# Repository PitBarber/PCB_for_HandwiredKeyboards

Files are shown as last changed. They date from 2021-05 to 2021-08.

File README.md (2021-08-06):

# PCB for Handwired Keyboards

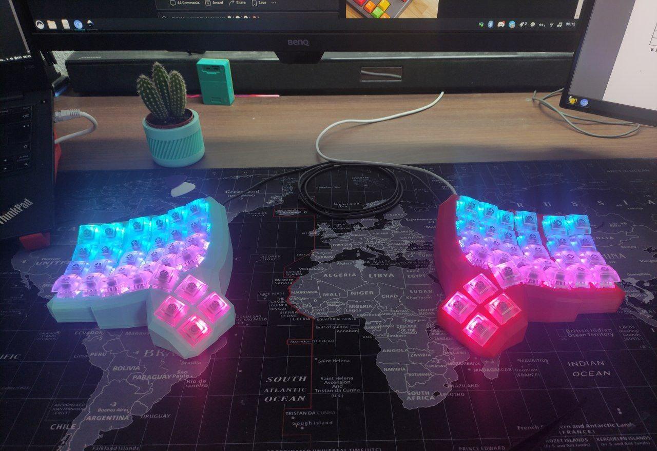
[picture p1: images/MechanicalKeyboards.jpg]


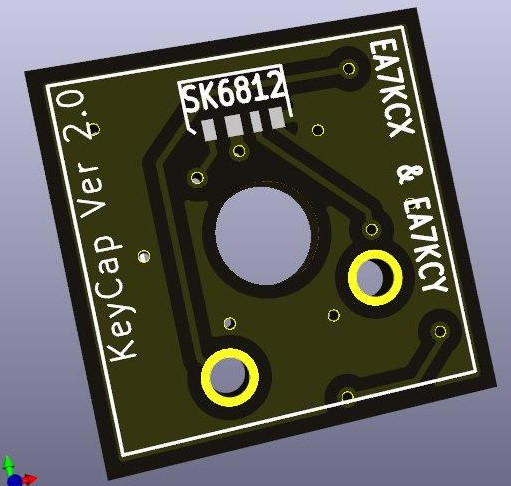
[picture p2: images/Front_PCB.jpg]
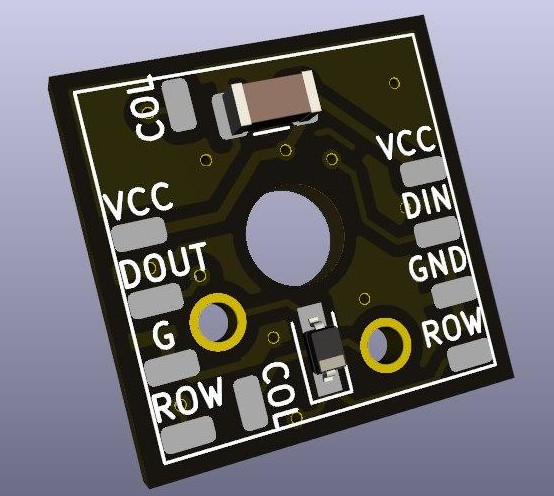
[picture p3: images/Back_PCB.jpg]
  

### About this repo:
```
Files you can find here are only the kicad project about the PCB design, 
3D design or entire keyboard firmware will be linked in this description.
```

### Why?

This project provides to handwired keyboards a support to have underglow keycaps.
PCBs was designed for keyboard with different form factors, for example: dactyl manuform. Its geometry makes makers hard to desing flexible PCBs, and them could be available only for some kind of dactyl manuform.
These 15mmx15mm PCBs are near to size of a keyboard Switch, so there can be placed in any custom keyboard, if a switch fits, a PCB will do it so, this is suitable for customizable keyboards.
Every PCB was designed with a LED neopixel, 100nF capacitor and a 1n4148 diode.

[3D design used in this project](https://github.com/joseandres42/dactyl-manuform-mini-keyboard) - 5x6 dactyl manuform 3D design por 3D printing by @joseandres42

In case you want to use the same design, @joseandres42 has a spanish dvorak layout
for this version of dactyl manuform [right in this forked repo](https://github.com/joseandres42/qmk_firmware/tree/master/keyboards/handwired/dactyl_manuform/5x6/keymaps/joseandres42)  

### The PCB 

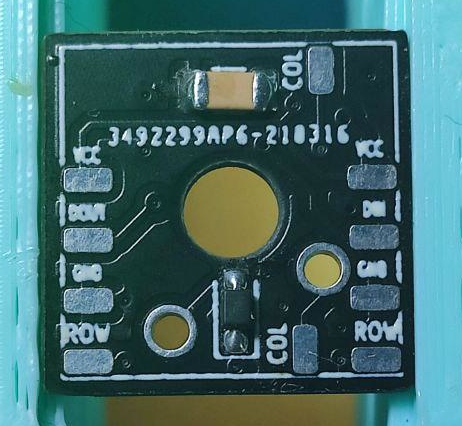
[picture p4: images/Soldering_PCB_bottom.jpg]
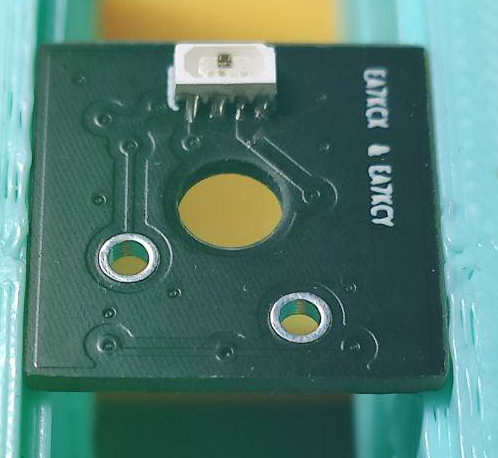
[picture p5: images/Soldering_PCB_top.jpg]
  

Handsoldering entire PCB is possible and i did it with the 62 PCBs.

Top of the PCB only has the builtin SK6812 4020 neopixel, they can be mounted sized or faceup. Footprint isn't in kicad's official libraries ( a merge will be done).

Bottom has a 100nF capacitor, necesary for the neopixel, a 1n4148 diode, for ROW to COL wiring ( remember it for the QMK config) and finally, the connection pads:
* VCC: 3.3-5v high level voltage node.
* DIN: Data In of the neopixel.
* DOUT: Data Out of the neopixel.
* GND: Ground node.
* COL: Column node.
* ROW: Row node.

### PCB TECHNICAL INFORMATION:

I will show you some technical data about boad sizes and LED SK6812 footprint:

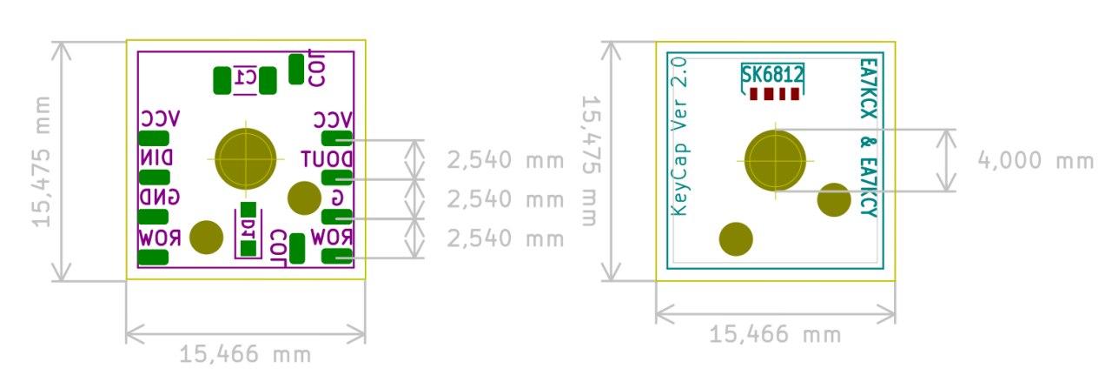
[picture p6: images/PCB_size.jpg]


Here you can see the size of the pcb, distance between pads and pads size.

Now, important information about SK6812 footprint, pads and sizes:

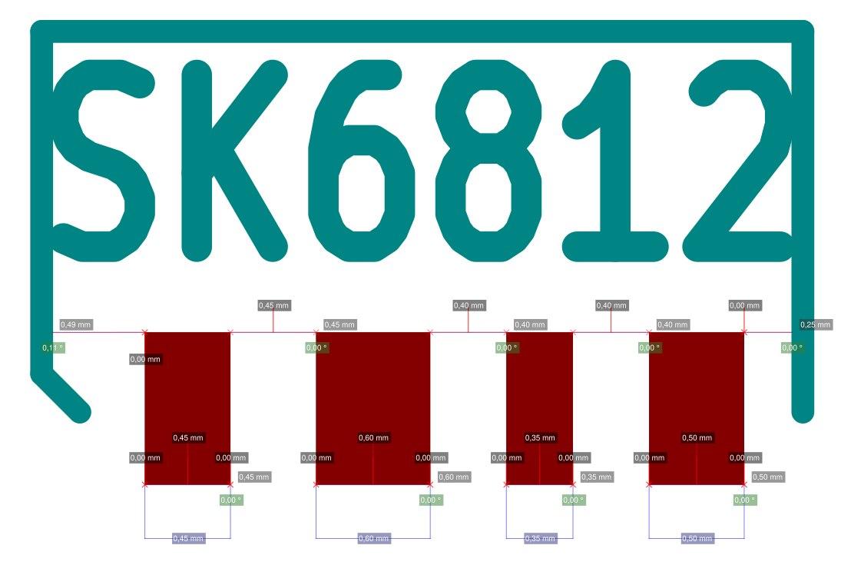
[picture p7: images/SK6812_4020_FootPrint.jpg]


This information is directly collected from official [SK6812 SIDE 4020 datasheet](http://www.normandled.com/upload/201804/SK6812%204020%20SIDE%20LED%20Datasheet.pdf)

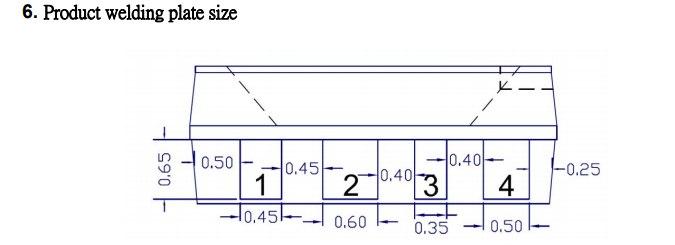
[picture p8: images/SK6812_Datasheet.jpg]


Footprint was designed using the FootPrint editing Tool provided by Kicad.

### Wiring
COL wiring:

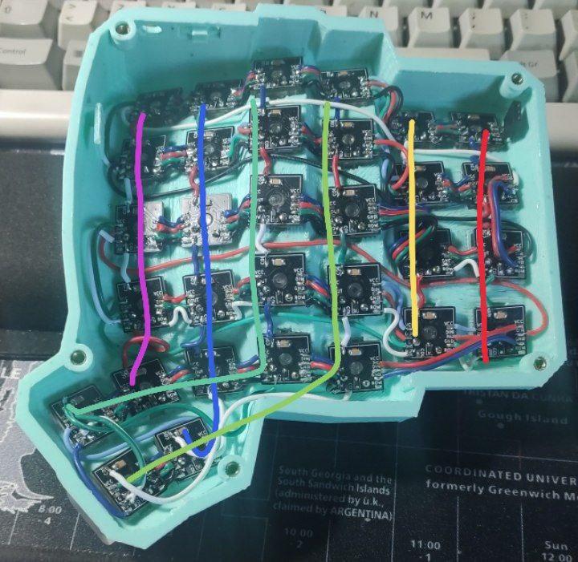
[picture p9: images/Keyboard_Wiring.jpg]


ROW wiring:

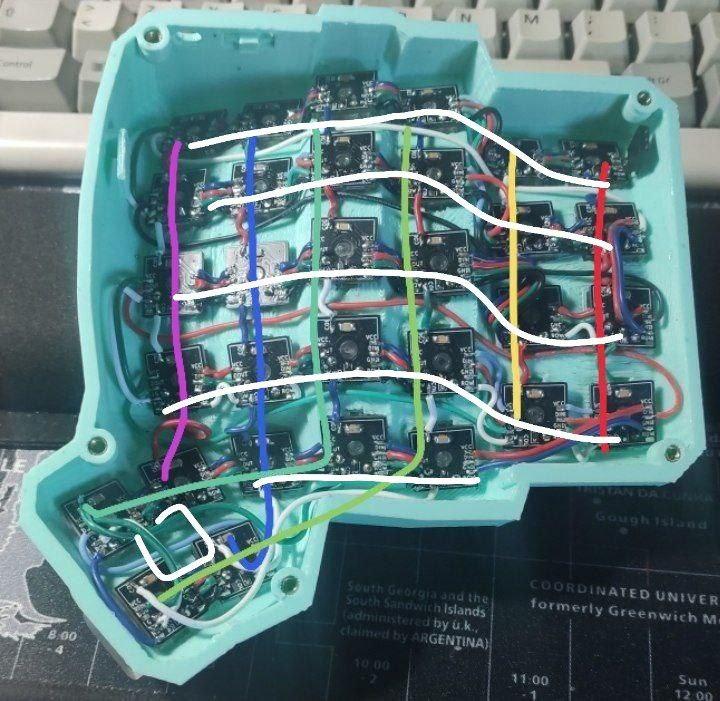
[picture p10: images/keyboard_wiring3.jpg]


This is the wiring in the lefthand keyboard, the righthand will be the same, but mirrored.

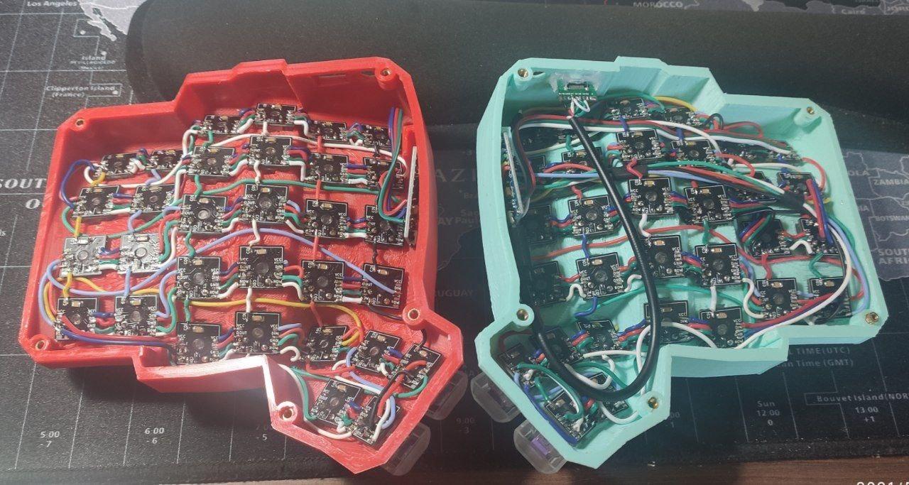
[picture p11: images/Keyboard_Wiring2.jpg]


* Boards Used: Arduino Pro micro in both cases
* [Oficial Dactyl Manuform](https://github.com/abstracthat/dactyl-manuform) - More wiring tips by @abstracthat

About the neopixel wiring, every DOUT is connected to de next DIN PCB node.

Be carefull with VCC and GND propagation, dont do it lineal, i mean, you can connect VCC and GND eachother, no matters the order.
But if you only have one connection to VCC at start and VCC propagates linear througt PCB it will experiment a fall of ~0.3V
that will cause some fliker due to less voltage feeding.

Best light brightness is between 80-110/255 when you config the lights in QMK.

[QMK neopixel documentation](https://github.com/qmk/qmk_firmware/blob/master/docs/feature_rgblight.md)- Neopixel animations and configuration tips

#### Config Example
```
#define DIODE_DIRECTION COL2ROW

// WS2812 RGB LED strip input and number of LEDs
#define	RGB_DI_PIN F4
#define	RGBLED_NUM 31

/* number of backlight levels */
#define RGBLIGHT_LIMIT_VAL 100
#define BACKLIGHT_LEVELS 3
```
More information at the provided link before.

### Firmware:

[QMK Firmware](https://github.com/qmk/qmk_firmware) - keyboard firmware based on the tmk_keyboard firmware

### Final Results:

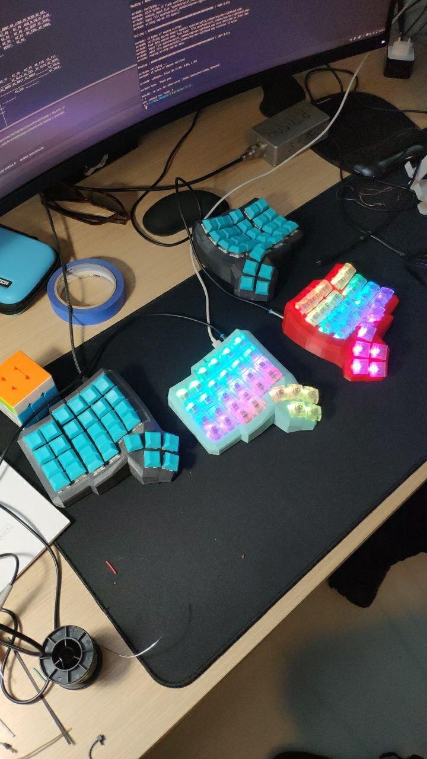
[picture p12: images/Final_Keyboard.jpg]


 

### Videos: 
Final result + ASMR siwtch video.

Dactyl Manuform with lights (https://www.youtube.com/watch?v=vpvnzlDXdoU)

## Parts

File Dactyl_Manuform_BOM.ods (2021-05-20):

Part | QTY | PRICE/U | FINAL PRICE | URL
PCB | 100 | 0,16 € | 15,56 € | http://www.jlcpcb.com
SK6812 4020 | 100 | 0,11 € | 10,99 € | https://es.aliexpress.com/item/33018587889.html
100nF Capacitor | 100 | 0,04 € | 3,89 € | https://es.aliexpress.com/item/1005002204832643.html
Diode 1n4148 (SOD-323) | 100 | 0,02 € | 1,89 € | https://es.aliexpress.com/item/4000331408283.html
Switches | 65 | 0,55 € | 35,62 € | https://es.aliexpress.com/item/32862816873.html
DSA KeyCaps | 68 | 0,16 € | 10,82 € | https://es.aliexpress.com/item/32830177884.html
Pro-Micro | 2 | 7,17 € | 14,34 € | https://es.aliexpress.com/item/32773740303.html
USB-C board (Female) | 2 | 1,51 € | 3,02 € | https://es.aliexpress.com/item/32951195698.html
Jack Port | 2 | 1,96 € | 3,92 € | https://es.aliexpress.com/item/32748752396.html
Stereo Jack cable | 1 | 1,17 € | 1,17 € | https://es.aliexpress.com/item/1005002133374052.html
Micro USB cable | 2 | 0,64 € | 1,27 € | https://es.aliexpress.com/item/4001350881049.html
Wiring Cable |  | Total | 102,49 €

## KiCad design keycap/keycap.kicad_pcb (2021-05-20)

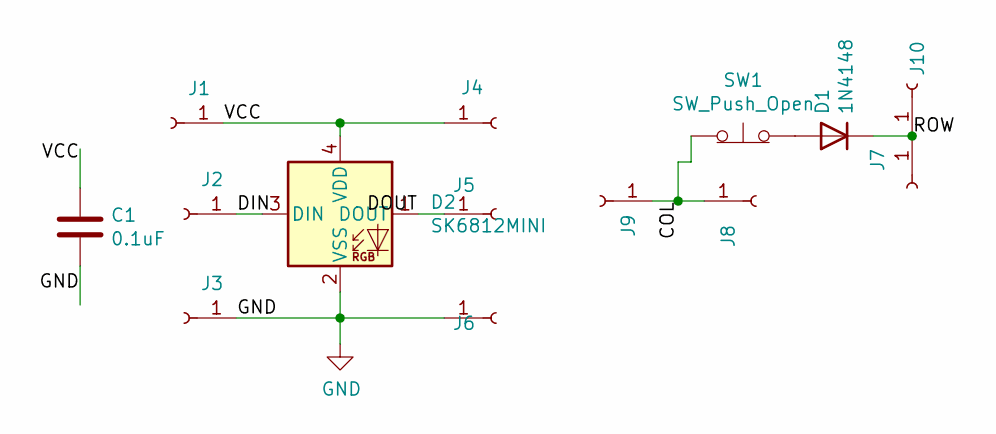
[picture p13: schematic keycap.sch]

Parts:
C1: 0.1uF; C_1206_3216Metric
D1: 1N4148; D_SOD-323_HandSoldering
D2: SK6812MINI; LED_SK6812MINI_PLCC4_3.5x3.5mm_P1.75mm
J1, J2, J3, J4, J5, J6, J7, J8, J9, J10: Conn_01x01_Female; SolderWirePad_1x01_SMD_1x2mm
SW1: SW_Push_Open; SW_Cherry_MX_1.00u_Plate

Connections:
/COL: J8.1, J9.1, SW1.1 (A)
/DIN: D2.3 (DIN), J2.1
/DOUT: D2.1 (DOUT), J5.1
/ROW: D1.1 (K), J7.1, J10.1
/VCC: C1.1, D2.4 (VDD), J1.1, J4.1
GND: C1.2, D2.2 (VSS), J3.1, J6.1
unnamed: D1.2 (A), SW1.2 (B)

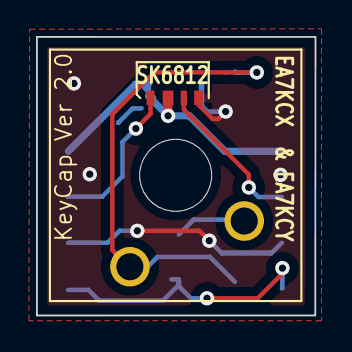
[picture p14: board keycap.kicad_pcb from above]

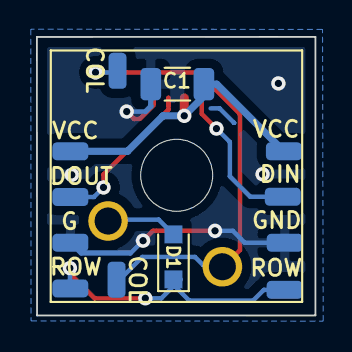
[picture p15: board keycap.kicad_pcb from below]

Board: 2 copper layers, 15.5 x 15.5 mm, 13 parts (12 on the bottom side), 5 nets.

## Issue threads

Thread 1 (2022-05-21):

Gerber files

zampierilucas, 2022-05-21:
Could you please add the gerber files?
As someone not from an electronics background Its hard to be certain if my conventions from kicad to gerber are correct.

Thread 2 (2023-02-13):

Can you update the PCB for the Neopixel SK6812-E?

Antebios, 2023-02-13:
It seems that the Neopixel SK6812B 4020 are both the older generation and out of stock, and the SK6812-E is newer and can shine through the key switches.  Are you going to update your PCB to use the newer led?

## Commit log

2021-05-20 Added images & BOM
    [Dactyl_Manuform_BOM.ods]
2021-05-26 PCB technical information
2021-05-26 Soldered PCBs
2021-05-26 Soldered PCBs edit
2021-05-27 deleted some files
    [keycap-B_Cu.gbr, keycap-B_Mask.gbr, keycap-B_Paste.gbr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]
